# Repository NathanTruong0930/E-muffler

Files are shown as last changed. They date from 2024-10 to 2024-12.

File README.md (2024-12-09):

**Exhaust System for Electric Vehicles**

This project aims to enhance the driving experience of electric vehicles by creating a system that mimics the sound of a traditional car engine. While electric vehicles are known for their quiet operation, some drivers miss the auditory feedback that comes with accelerating and driving. Our solution is a customizable exhaust system that produces realistic engine sounds and visually engages the user with LED indicators.

At the heart of the system is a custom-designed circuit board (PCB) that integrates key components like speakers, LEDs, touch sensors, and a throttle positioning sensor. The sounds are stored on a microSD card and played through dual speakers. One speaker produces a constant background hum, while the other changes its volume based on the throttle position, simulating acceleration. The system also features LED lights to indicate power status and track selection.

The exhaust system is user-friendly and easy to control. A touch sensor lets the user turn the system on and off, while another sensor allows switching between different engine sound profiles. The LED lights indicate whether the system is on and show which sound profile is currently active. Powered by a standard 9V battery, the entire setup is compact enough to fit inside an exhaust-like enclosure, making it ideal for integration into an electric vehicle.

This project combines practical engineering with creativity, offering a solution that balances the silence of electric vehicles with the sensory experience of traditional cars. Whether you’re a car enthusiast or just someone looking for a fun way to personalize your EV, this exhaust system brings sound and style to the future of driving.

Team members:
- Nathan Truong
- Eisa ALsharifi
- Aziz Alshaanban
- Fernando Custodio Calderon

Project Schedule - [Gantt Chart](https://pdx127928.monday.com/boards/7800402463)

Note: The archive folder contains older revisions of homework files.

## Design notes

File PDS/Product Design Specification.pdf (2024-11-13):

ECE 411 Product Design Specification Team 14
Version 2.0
Nathan Truong, Eisa Alsharifi, Aziz Alshaanban, Fernando Custodio Calderon

Nov 13, 2024

Create a PDS for your practicum project, and upload it to your collaboration site. Sections should include:

Electric Vehicle Sound Muffler

Our product the Electric vehicle sound muffler is a device that makes electric vehicles sound like traditional gas powered cars. It’s designed for people with electric vehicles who want to have their vehicles sound like a traditional vehicle that has a powerful, loud engine.
Our product uses an accelerometer and a throttle position sensor to track the car's speed and movement. These sensors send information to the Arduino Uno. The sounds are played through speakers, allowing an engine revving noise to be heard that changes as the vehicle speeds up or slows down. Once installed, the muffler works automatically, generating powerful engine sounds as the vehicle drives. It gives drivers a more engaging experience, making it less boring when going on a ride. You won’t be bored with the sound of silence while driving anymore.

Our intended customers are anyone who has an electric vehicle and would like to have a better driving experience by adding the sound of a traditional car. Also our product would be great for just any car enthusiast.
Our main competition would be competitors who make third party noise systems and other types of sound generators made for electric vehicles. Our product stands out because it will use real-time sound based on how a vehicle is performing, thus making it feel like a more authentic experience.
Our product will be sold for somewhere between $200 - 300. We chose this price because it will cover the price of our components and remain affordable enough for anyone looking to enhance their driving experience in their electric vehicle.
- Requirements:
- The device MUST be compact and lightweight, SHOULD be easy to install. A complete beginner should be able to learn how to install this device in 10-15 minutes of reading the manual.
- The device MUST have low power consumption to avoid affecting the vehicle performance, SHOULD use energy-efficient components and sound amplification circuits. It MAY use a solar charging system or a rechargeable battery.
- The Sound frequency MUST be clear and realistic to match the accelerometer even at higher volumes. The product MUST be fully automated and reflects the real-time throttle data as well as the speed of the vehicle using CAN bus
- Safety is a MUST, It will have water resistance incase of rain and proper insulation incase of heat. To prevent any potential fire hazards.
- The total cost of the product should fall within the $200-300 price range.

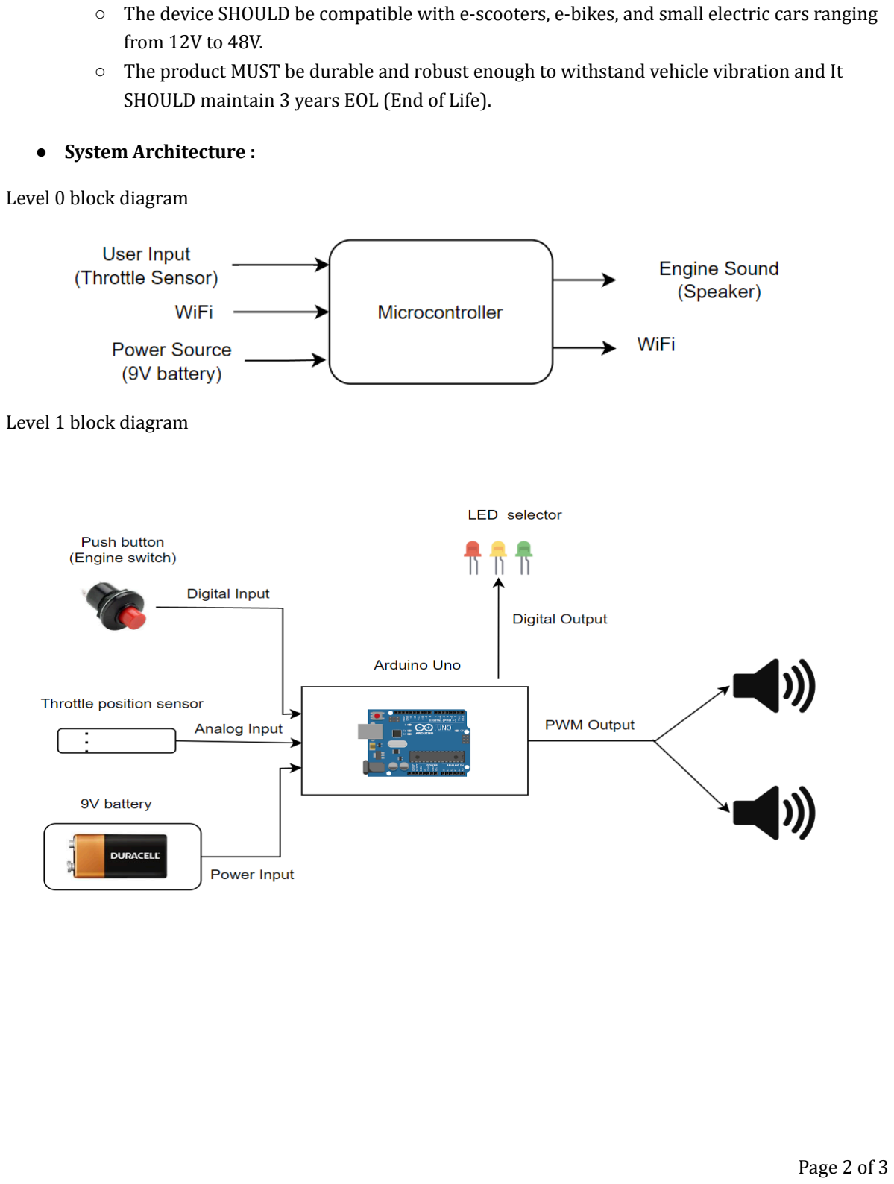
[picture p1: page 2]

- The device SHOULD be compatible with e-scooters, e-bikes, and small electric cars ranging from 12V to 48V.
- The product MUST be durable and robust enough to withstand vehicle vibration and It SHOULD maintain 3 years EOL (End of Life).
- System Architecture :

Level 0 block diagram

Level 1 block diagram

- Design Specification

❖ Sensors:
- Throttle Position Sensor: Simulates throttle input to determine the intensity of engine sound variations based on the vehicle’s simulated speed.
❖ Processor:
- Arduino Uno: Built into the custom PCB to process sensor data and produce required audio signals. The design contains all of the Arduino Uno's supporting components on the PCB.
❖ Actuator:
- 2 Speakers in Exhaust: The speakers will be installed inside an exhaust structure to replicate the acoustic environment of a traditional car exhaust. This setup will mimic sound propagation and improve the realistic feel of the created engine sounds.
- Audio Amplifier: The PCB will feature an amplifier that boosts audio signals before they are sent to the speakers.
❖ Power:
- 9V Battery: The entire system will be powered by a 9V battery, with onboard voltage regulation circuits to step down the voltage appropriately for the microcontroller, Wi-Fi module, and other components.
❖ Mechanical Design:
- The custom-designed PCB will be safely contained in the exterior like a car exhaust. The throttle position sensor will be programmed to collect precise data to power the sound generating algorithm.
❖ Firmware:
- The firmware on the Arduino Uno will process sensor data and make engine noises in response to simulated vehicle settings. The code will incorporate algorithms for making real-time sound modifications in response to changes in throttle input.
- The Wi-Fi module allows for remote monitoring or control, providing users to configure or alter sound parameters via a remote control.
❖ Development Environment:
- Arduino IDE: The firmware will be developed using the Arduino IDE, with an ICSP programmer used for uploading the code to the integrated Arduino Uno.
- Signal Processing Libraries: Custom libraries will be used to process data from sensors, generate sounds, and communicate over Wi-Fi.

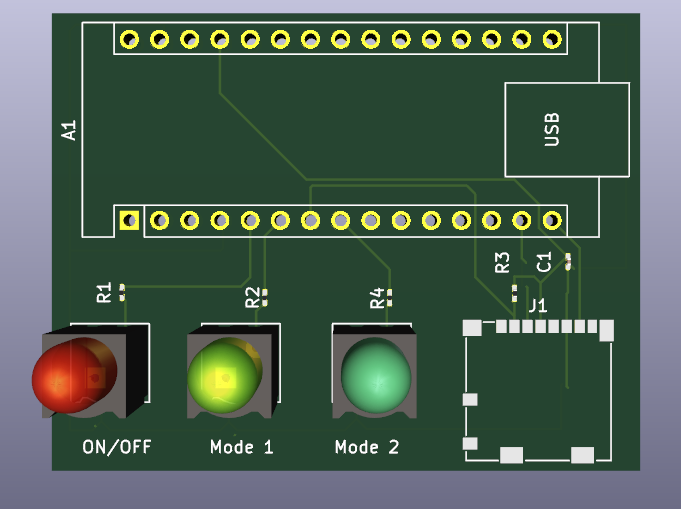
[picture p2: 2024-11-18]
Schematics/PCB-3D-View.PNG

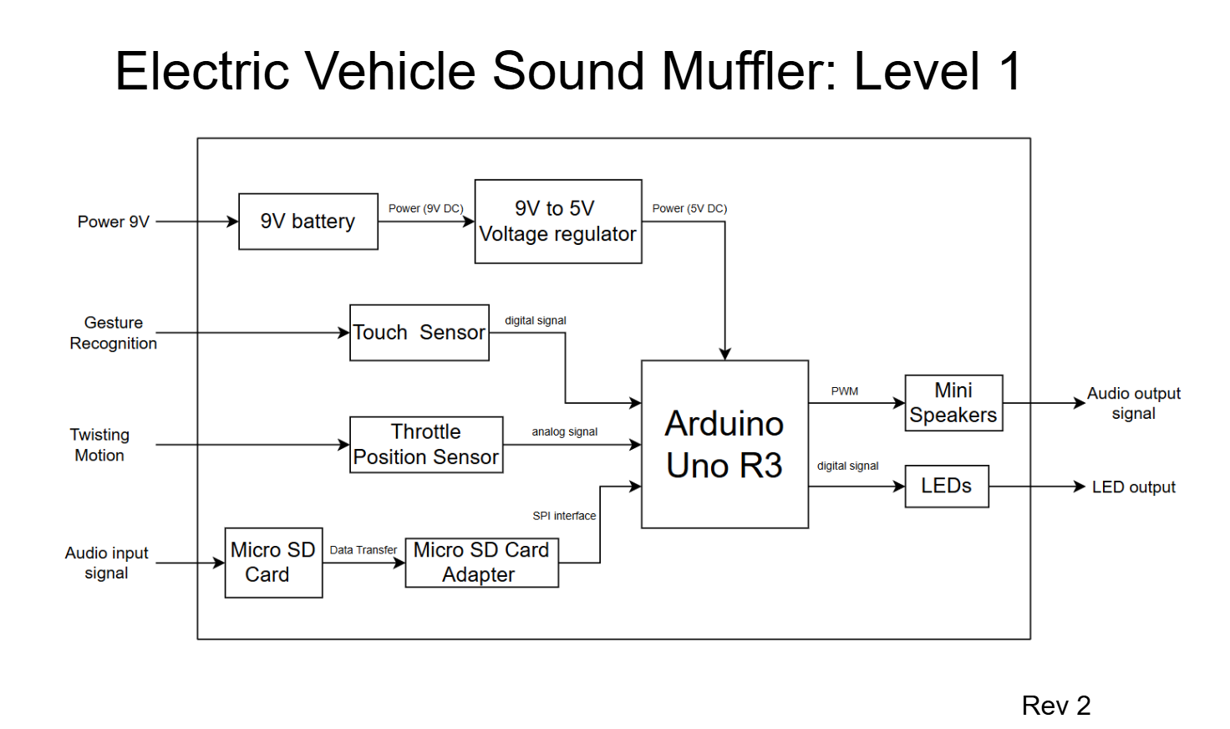
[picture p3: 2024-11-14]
Block Diagrams/L1 Diagram.png

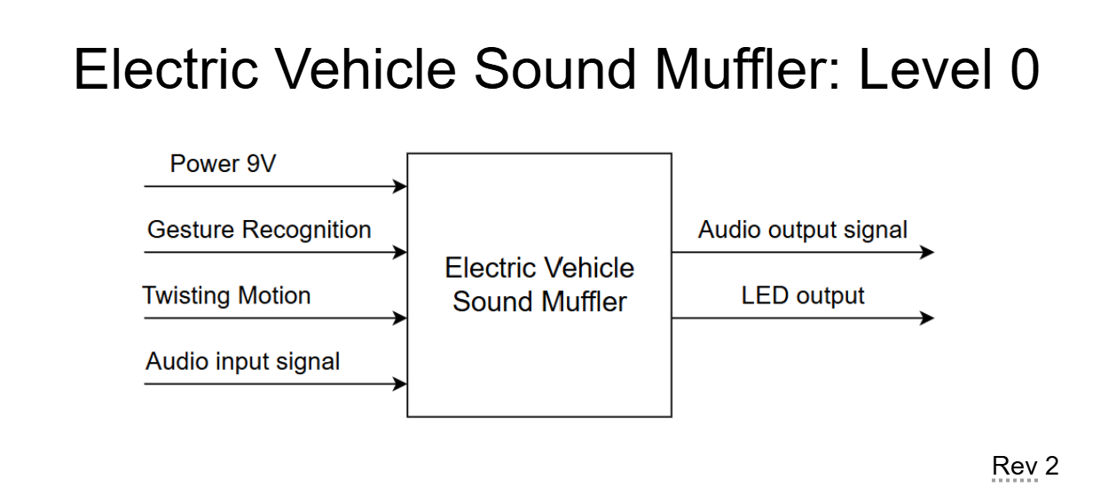
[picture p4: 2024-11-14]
Block Diagrams/L0 Diagram.png

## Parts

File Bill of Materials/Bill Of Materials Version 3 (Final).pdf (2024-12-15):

P/NP
Cnt Part References | P/NP | Mfg | Mfg PN | Description | Dist | Dist Part Number | Cost Total Datasheet
1 | A1 | P | LAFVIN | A000005 | x3 Nano V3.0, Nano Board ATmega328P 5V 16M Micro-Controller Board Compatible with Arduino IDE (Nano x 3 with USB Cable) Amazon | B07G99NNXL | $15.99 https://mm.digikey.com/Volume0/opasdata/d220001/medias/docus/382/A000005.pdf
1 | C1 | P | Murata Electronics | GRM31CR60J107KEA8L | CAP CER 100UF 6.3V X5R 1206 | Digi-Key | 490-GRM31CR60J107KEA8LCT-ND $0.54 https://search.murata.co.jp/Ceramy/image/img/A01X/G101/ENG/GRM31CR60J107KEA8-01A.pdf
1 | C2 | P | KEMET | C1206X106J3RACAUTO | CAP CER 10UF 25V X7R 1206 | Digi-Key | 399-15736-1-ND | $1.59 https://search.kemet.com/download/datasheet/C1206X106J3RACAUTO
1 | J1 | P | Molex | 1040310811 | 10 (8 + 2) Position Card Connector Secure Digital - microSD™ Surface Mount, Right Angle Gold Digi-Key | WM6357CT-ND | $2.30 https://www.molex.com/en-us/products/part-detail/1040310811?display=pdf
3 | R1, R2, R4 | P | Panasonic Electronic Components | ERJ-6ENF2200V | RES SMD 220 OHM 1% 1/8W 0805 | Digi-Key | P220CCT-ND | $0.052
3 | R3, R5, R6 | P | Panasonic Electronic Components | ERJ-6ENF1001V | RES SMD 1K OHM 1% 1/8W 0805 | Digi-Key | P1.00KCCT-ND | $0.052 https://industrial.panasonic.com/cdbs/www-data/pdf/RDA0000/AOA0000C304.pdf
1 | U1 | NP | SWCTSY | SW765071651710 | E-Bike Throttle Grip | Amazon | 765071651710 | $14.58 https://industrial.panasonic.com/cdbs/www-data/pdf/RDA0000/AOA0000C304.pdf
1 | U2, U3 | NP | Adafruit | 1375 | Standalone Toggle Capacitive Touch Sensor Breakout Adafruit | AT42QT1012 | $0.33
1 | U4 | P | Texas Instruments | LM7805CT/NOPB | IC REG LINEAR 5V 1A TO220-3 | Digi-Key | 296-47192-ND | $1.74 https://www.ti.com/lit/ds/symlink/lm7800.pdf
1 | LED1 | P | Dialight | 5612101060F | LED CBI 5MM RED TH PC MNT | Digi-Key | 350-2813-ND | $1.43 https://mm.digikey.com/Volume0/opasdata/d220001/medias/docus/932/561-zz0z-zzz.pdf
1 | LED2 | P | Dialight | 5612201060F | LED CBI 5MM GRN TH PC MNT | Digi-Key | 350-2374-ND | $1.52 https://mm.digikey.com/Volume0/opasdata/d220001/medias/docus/932/561-zz0z-zzz.pdf
1 | LED3 | P | Dialight | 5612301060F | LED CBI 5MM YELLOW TH PC MNT | Digi-Key | 350-3148-ND | $1.43 https://mm.digikey.com/Volume0/opasdata/d220001/medias/docus/932/561-zz0z-zzz.pdf
1 | SL, SR | NP | Esooho | EK1725 | Gikfun 2" 4Ohm 3W Full Range Audio Speaker Stereo Woofer Amazon | B01CHYIU26 | $9.99 https://www.amazon.com/Gikfun-Speaker-Stereo-Loudspeaker-Arduino/dp/B01CHYIU26
3 | Vbattery | NP | ZEUS Battery Products | ZEUS 9V | BATTERY ALKALINE 9V | Digi-Key | 2059-ZEUS9V-ND | $2.00 https://www.zeusbatteryproducts.com/wp-content/uploads/downloads/Zeus_Alkaline_9V_RevV2_spec_sheet.pdf
1 | VBat1 | P | Keystone Electronics | 81-4 | BATT CONNECTOR SNAP 9V 4" LEADS | Digi-Key | 36-81-4-ND | $0.67 https://www.keyelco.com/userAssets/file/M65p30.pdf
3 | U1, U2, U3 | P | Amphenol ICC | G800W305018EU | PIN HEADER 2.54MM PITCH STR,1X3P | Digi-Key | 664-G800W305018EU-ND$0.062 https://cdn.amphenol-cs.com/media/wysiwyg/files/drawing/g800wxxxxxxeu_1.pdf
3 | LS1, LS2 | P | Amphenol ICC | G800W306018EU | PIN HEADER 2.54MM PITCH STR,1X2P | Digi-Key | 664-G800W306018EU-ND$0.046 https://cdn.amphenol-cs.com/media/wysiwyg/files/documentation/datasheet/boardwiretoboard/bwb_btb_254_g800.pdf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
1 | EXH | NP | A-KARCK | N-ATP355012RACB | A-KARCK Exhaust Tip 3.5 Inch Inlet, 3.5” Inlet 5" Outlet 12" Long Stainless Steel Polished Finish Tailpipe Tip, Bolt On Design Amazon | 8.83343E+11 | $27.99 https://www.amazon.com/dp/B08CXNYXHZ?ref=ppx_yo2ov_dt_b_fed_asin_title&th=1
1 | Micro SD Card | P | MCG Bear LTD | SDSQUNB-032G-GN3MN SanDisk 32GB 32G Ultra Micro SD HC Class 10 TF Flash SDHC Memory Card - SDSQUNB-032G-GN3MN Amazon | B010NE3QHQ | $7.82 https://www.amazon.com/SanDisk-Ultra-SDSQUNB-032G-GN3MN-UHS-I-microSDHC/dp/B010NE3QHQ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
15 | Jumper Wires | P | | | | EPL | | $7.50
1 | PCB (OSH Park ~) | | | | | | | $8.18
1 | Shipping & Tariff | | | | | | | $20.41
| | | | | | | TOTAL: | $126.22

Bill Of Materials for: TEAM14, Exhaust System for Electric Vehicles
Last modified: 12-12-2024
PCB version: PCB VERSION #3
BOM revision: BOM REVISION #4 | = Place/Not Place (components marked NP are not stuffed on the board)

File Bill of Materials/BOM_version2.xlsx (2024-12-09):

Bill Of Materials for: TEAM14, Exhaust system for electric cars
Last modified: 11-14-2024
PCB version: PCB VERSION #1
BOM revision: BOM REVISION #1 |  | P/NP | = Place/Not Place (components marked NP are not stuffed on the board)
.
Cnt | Part References | P/NP | Mfg | Mfg PN | Description | Dist | Dist Part Number | Cost Ea. | Cost Total | Datasheet
1 | A1 | P | LAFVIN | A000005 | x3 Nano V3.0, Nano Board ATmega328P 5V 16M Micro-Controller Board Compatible with Arduino IDE (Nano x 3 with USB Cable) | Amazon | B07G99NNXL | $15.99 | $15.99 | https://mm.digikey.com/Volume0/opasdata/d220001/medias/docus/382/A000005.pdf
4 | C1 | P | Murata Electronics | GRM31CR60J107KEA8L | CAP CER 100UF 6.3V X5R 1206 | Digi-Key | 490-GRM31CR60J107KEA8LCT-ND | $0.54 | $2.16 | https://search.murata.co.jp/Ceramy/image/img/A01X/G101/ENG/GRM31CR60J107KEA8-01A.pdf
10 | C1 | P | Murata Electronics | 490-10387-1-ND | CAP CER 0.1UF 16V X7S 0201 | Digi-Key | 490-10387-1-ND | $0.018 | $0.18 | https://search.murata.co.jp/Ceramy/image/img/A01X/G101/ENG/GRM033C71C104KE14-01.pdf
4 | C2 | P | KEMET | C1206X106J3RACAUTO | CAP CER 10UF 25V X7R 1206 | Digi-Key | 399-15736-1-ND | $1.59 | $6.36 | https://search.kemet.com/download/datasheet/C1206X106J3RACAUTO
3 | J1 | P | Molex | 1040310811 | 10 (8 + 2) Position Card Connector Secure Digital - microSD™ Surface Mount, Right Angle Gold | Digi-Key | WM6357CT-ND | $2.30 | $6.90 | https://www.molex.com/en-us/products/part-detail/1040310811?display=pdf
2 | Q1, Q2 | P | Onsemi | LM317TG | Linear Regulators (LDO) | LM317 used for speakers | Digi-Key | LM317TG | $1.41 | $2.82
12 | R1, R2, R4 | P | Panasonic Electronic Components | ERJ-6ENF2200V | RES SMD 220 OHM 1% 1/8W 0805 | Digi-Key | P220CCT-ND | $0.052 | $0.62 | https://industrial.panasonic.com/cdbs/www-data/pdf/RDA0000/AOA0000C304.pdf
10 | R1, R2, R3 | P | Vishay Dale | CRCW0201220RFNED | 220 Ohms ±1% 0.05W, 1/20W Chip Resistor 0201 (0603 Metric) Thick Film | Digi-Key | 541-CRCW0201220RFNEDCT-ND | $0.038 | $0.38 | https://www.vishay.com/docs/20052/crcw0201e3.pdf
10 | R3, R5, R6 | P | Panasonic Electronic Components | ERJ-6ENF1001V | RES SMD 1K OHM 1% 1/8W 0805 | Digi-Key | P1.00KCCT-ND | $0.052 | $0.52 | https://industrial.panasonic.com/cdbs/www-data/pdf/RDA0000/AOA0000C304.pdf
4 | R1 | P | Vishay Dale | CRCW02011K00FKED | 1 kOhms ±1% 0.05W, 1/20W Chip Resistor 0201 (0603 Metric) Thick Film | Digi-Key | 541-1.00KAABCT-ND | $0.23 | $0.92 | https://www.vishay.com/docs/20052/crcw0201e3.pdf
1 | U1 | NP | SWCTSY | ‎SW765071651710 | E-Bike Throttle Grip | Amazon | ‎765071651710 | $14.58 | $14.58
1 | U2 | NP | Adafruit | 1375 | Standalone Toggle Capacitive Touch Sensor Breakout | Adafruit | AT42QT1012 | $0.33 | $0.33
3 | U4 | P |  |  |  |  |  |  | $0.00
3 | U4 | P | Texas Instruments | LM7805CT/NOPB | IC REG LINEAR 5V 1A TO220-3 | Digi-Key | 296-47192-ND | $1.74 | $5.22 | https://www.ti.com/lit/ds/symlink/lm7800.pdf
1 | Vhold | P | Adafruit | 80 | 9V battery clip with 5.5mm/2.1mm plug | Adafruit | 80 | $2.95 | $2.95
1 | VBat1 | P | Adafruit | 1321 | Alkaline 9V Battery | Digi-Key | 1321 | $1.50 | $1.50
3 | LED1 | P | Dialight | 5612101060F | LED CBI 5MM RED TH PC MNT | Digi-Key | 350-2813-ND | $1.43 | $4.29 | https://mm.digikey.com/Volume0/opasdata/d220001/medias/docus/932/561-zz0z-zzz.pdf
3 | LED2 | P | Dialight | 5612201060F | LED CBI 5MM GRN TH PC MNT | Digi-Key | 350-2374-ND | $1.52 | $4.56 | https://mm.digikey.com/Volume0/opasdata/d220001/medias/docus/932/561-zz0z-zzz.pdf
3 | LED3 | P | Dialight | 5612301060F | LED CBI 5MM YELLOW TH PC MNT | Digi-Key | 350-3148-ND | $1.43 | $4.29 | https://mm.digikey.com/Volume0/opasdata/d220001/medias/docus/932/561-zz0z-zzz.pdf
1 | LS1, LS2 | NP | Esooho | EK1725 | Gikfun 2" 4Ohm 3W Full Range Audio Speaker Stereo Woofer | Amazon | B01CHYIU26 |  | $0.00
3 | Vbattery | NP | ZEUS Battery Products | ZEUS 9V | BATTERY ALKALINE 9V | Digi-Key | 2059-ZEUS9V-ND | $2.00 | $6.00 | https://www.zeusbatteryproducts.com/wp-content/uploads/downloads/Zeus_Alkaline_9V_RevV2_spec_sheet.pdf
3 | VBat1 | P | Keystone Electronics | 81-4 | BATT CONNECTOR SNAP 9V 4" LEADS | Digi-Key | 36-81-4-ND | $0.67 | $2.01 | https://www.keyelco.com/userAssets/file/M65p30.pdf
10 | U1, U2, U3 | P | Amphenol ICC | G800W305018EU | PIN HEADER 2.54MM PITCH STR,1X3P | Digi-Key | 664-G800W305018EU-ND | $0.062 | $0.62 | https://cdn.amphenol-cs.com/media/wysiwyg/files/drawing/g800wxxxxxxeu_1.pdf
10 | LS1, LS2 | P | Amphenol ICC | G800W306018EU | PIN HEADER 2.54MM PITCH STR,1X2P | Digi-Key | 664-G800W306018EU-ND | $0.046 | $0.46 | https://cdn.amphenol-cs.com/media/wysiwyg/files/documentation/datasheet/boardwiretoboard/bwb_btb_254_g800.pdf
1 | Shipping & Tariff (First order) |  |  |  |  |  |  |  | $14.04
1 | Shipping & Tariff (Second order) |  |  |  |  |  |  |  | $13.41
VERSION INFO
 |  | Notes |  |  |  |  |  | TOTAL: | $111.11
Rev | Date | Cleaned up parts, rough draft of board
1.0r1 | 2024-11-14 | Initial BOM. Not everything chosen.
1.0r0 | 2020-11-12

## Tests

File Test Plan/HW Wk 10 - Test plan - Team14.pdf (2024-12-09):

ECE 411 Product Design Specification Team 14
Version 1.0
Nathan Truong, Eisa Alsharifi, Aziz Alshaanban, Fernando Custodio Calderon

Dec 08, 2024
Test Case

Test Author: Team 14
Test Case Name: | PCB Soldering Testing and Open Circuit Verification | Test ID #: | PCB-SOLDER-01
Description: | This test case focuses on verifying proper soldering of all PCB components, including resistors, capacitors, LEDs, and the SD card module. It ensures that all connections are free from open circuits, shorts, or improperly placed components. The test also includes steps to fix common issues such as flipped LEDs, poorly soldered components, or misaligned parts. | Type: | white box black box

Tester Information
| Name of Tester: | Eisa Alsharifi | Date: | 12/06/2024
| HW/SW Version: | 1.0 | Time: | 1:10-5:15 pm
| Setup: | Prepare a multimeter for continuity and voltage checks. Have a soldering station ready for rework. Connect a 9V battery to VBAT1 for power testing.
S T E P | Action | Expected Result | P A S S | F A I L | N / A | Comments
1 | Inspect solder joints on resistors (R1–R3). | All joints are clean and have no cold soldering or bridging. | ✔ | | | Resoldered R2 due to a cold joint.
2 | Inspect solder joints on capacitors (C1, C2). | Capacitors are soldered properly, with no open circuits or shorts. | ✔ | | | No issues detected.
3 | Check LED polarities and solder joints. | LEDs (R1, G1, Y1) are soldered properly; cathodes are not flipped. | | ✔ | | Cathode of LED R1 was flipped, fixed and retested.
2023-11-28 | Page 1 of 4

4 | Resolder flipped LED (if detected). | LED lights up correctly when powered. | ✔ | Verified LED R1 functionality after rework.
5 | Inspect SD card module soldering. | SD card pins are aligned and properly soldered with no open circuits. | ✔ | Pin alignment was off; resoldered successfully.
6 | Check for open circuits with a multimeter. | All resistors and capacitors show proper continuity. | ✔ | Continuity verified for all components.
7 | Test power delivery to the PCB. | 5V output is stable, with no shorts causing excessive current draw. | ✔ | Measured stable 5V output from Arduino Nano.
8 | Insert SD card and test initialization. | SD card initializes successfully, and data can be read. | ✔ | Initialization successful, SD card works as expected.
9 | Verify signal continuity for LEDs. | Multimeter shows continuity from the Arduino Nano to the LEDs. | ✔ | All LED connections verified.
| Overall test result: | | ✔ | Successful assembly

Matrix Test (for varying parameters)

Test Author: Team 14

Test Case Name: | PCB Testing and Component Verification | Test ID #: | PCB-TEST-01
Description: | This test case focuses on debugging the PCB build to ensure that all components are correctly soldered, powered, and function as intended. The test will verify the connections for power supply, LEDs, speakers, microSD card, and Arduino Nano integration. | Type: | white box black box

Tester Information

| Name of Tester: | Eisa Alsharifi | Date: | 12/06/2024
| HW/SW Version: | 1.0 | Time: | 6:10-10:15 AM
| Setup: | ● Power the PCB with a 9V battery via VBAT1. ● Connect a pre-programmed Arduino Nano. ● Ensure components (e.g., LEDs, speakers, microSD module) are properly soldered and connected. ● Use a multimeter and an oscilloscope for voltage and signal verification.
T ES T | INPUTS | EXPECTED OUTPUTS | P A S S | F A I L | N / A | Comments
1 | Inspect all solder joints visually. | No cold solder joints, shorts, or bridges are visible. | ✔ | | | All look good
2 | Power ON the PCB with 9V battery. | Verify 5V and 3.3V output at Arduino Nano pins. | ✔ | | | We indeed get 5V and 3.3V
3 | Check VBAT1 voltage with multimeter. | VBAT1 shows ~9V from battery. | | | ✔ | Wasn’t tested

4 | Check voltage at each LED pin. | LED pins should show expected voltage (e.g., ~2V for forward voltage). | | ✔ | We’re not able to get any readings to any LED
5 | Verify speaker connections (LS1, LS2). | Output terminals show audio signal when Arduino sends sound. | | ✔ | We get no sound, not even noise
6 | Test microSD card module functionality. | MicroSD is initialized, and files are accessible. | | ✔ | The adapter is soldered improbably
7 | Check throttle input (A0 pin). | Voltage changes as throttle sensor is adjusted. | ✔ | | We can get readings from the throttle
8 | Test ON/OFF touch sensor functionality. | LED toggles correctly between ON/OFF states. | | ✔ | It is powered, but doen’t function properly
9 | Test mode change touch sensor. | LEDs correctly indicate current track; audio switches accordingly. | | ✔ | It is powered, but doen’t function properly
10 | Adjust throttle to test volume control. | Speaker 1 volume adjusts with throttle input. | | ✔ | The readings are a bit off to were we wanted it to be
| Overall test result: | | | ✔ | We’ll fix all the issues and retest

Next testing will be on 12/10/2024 in the morning.

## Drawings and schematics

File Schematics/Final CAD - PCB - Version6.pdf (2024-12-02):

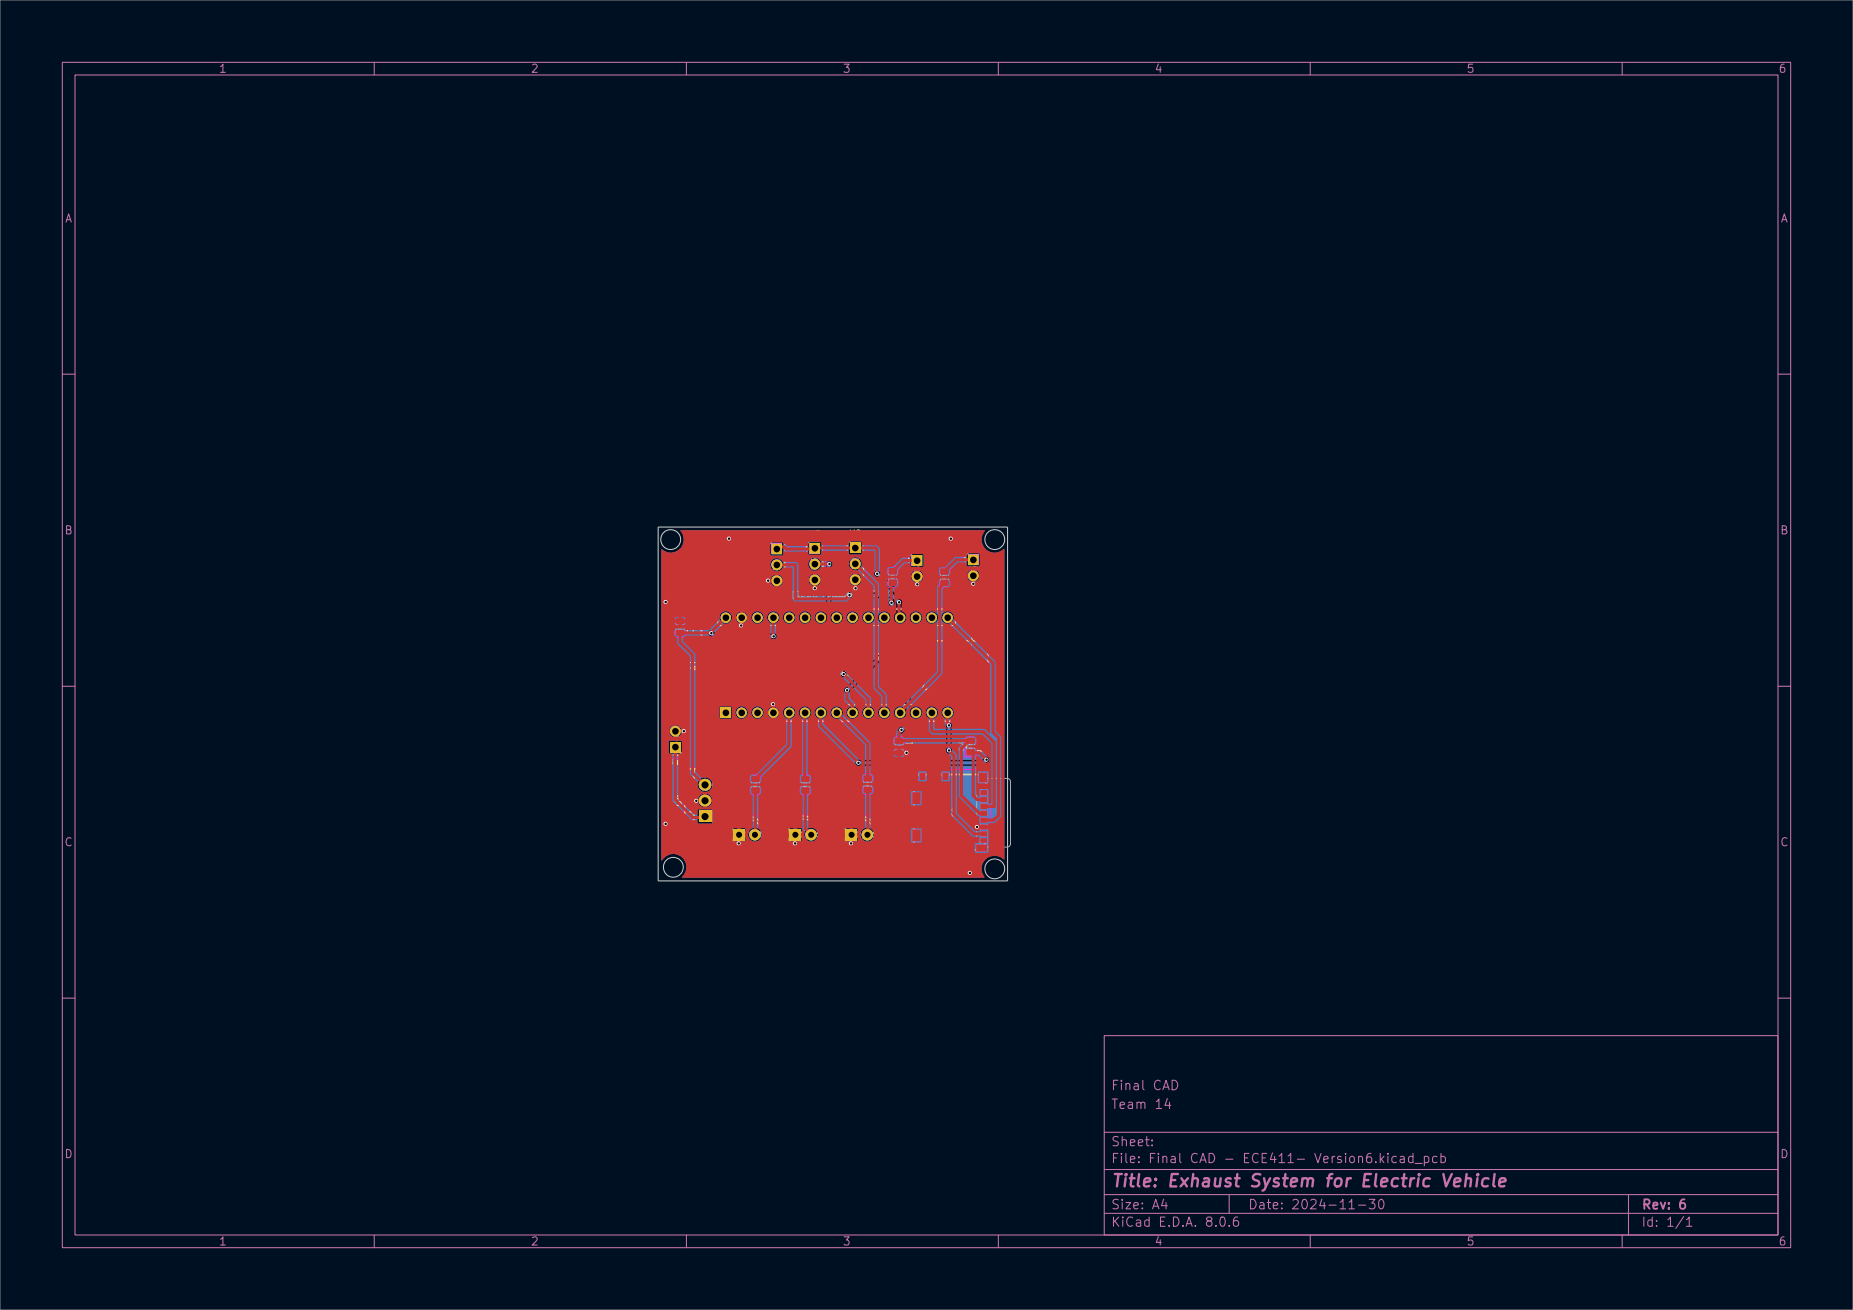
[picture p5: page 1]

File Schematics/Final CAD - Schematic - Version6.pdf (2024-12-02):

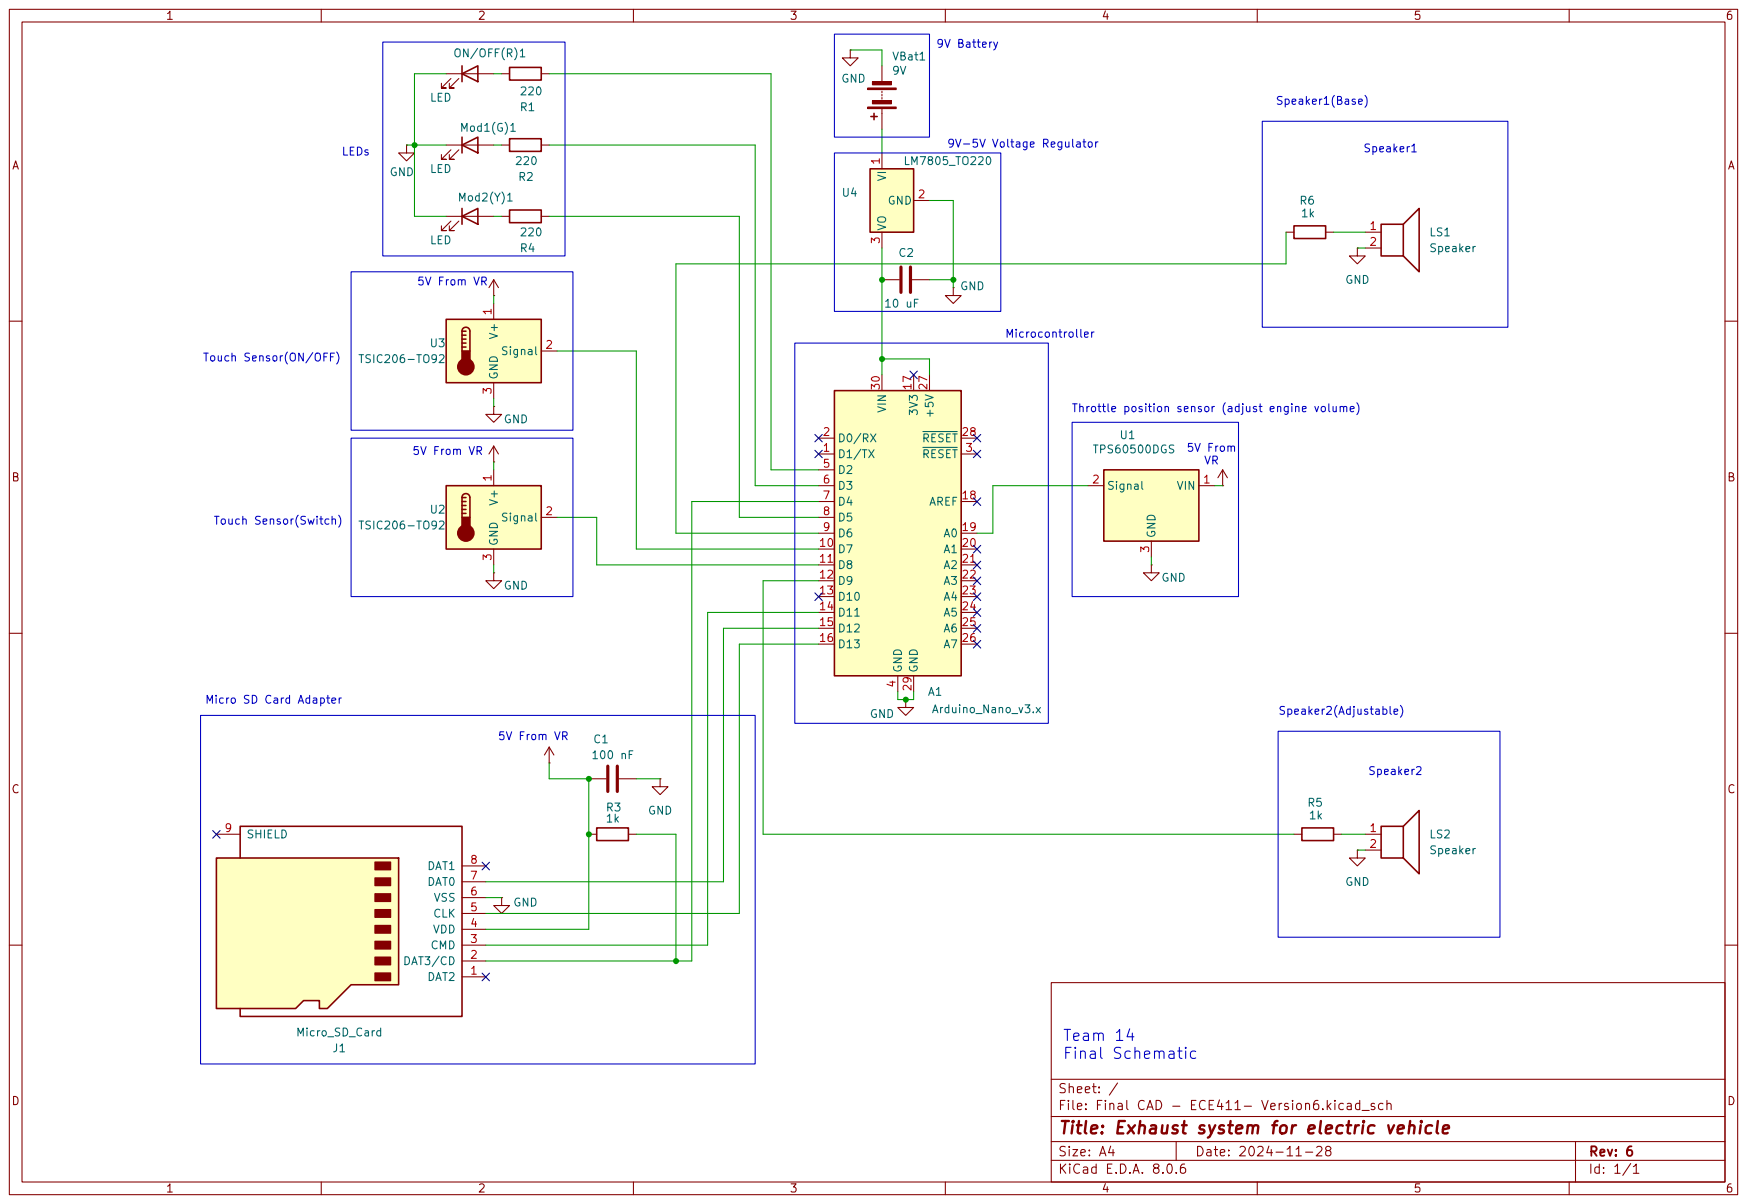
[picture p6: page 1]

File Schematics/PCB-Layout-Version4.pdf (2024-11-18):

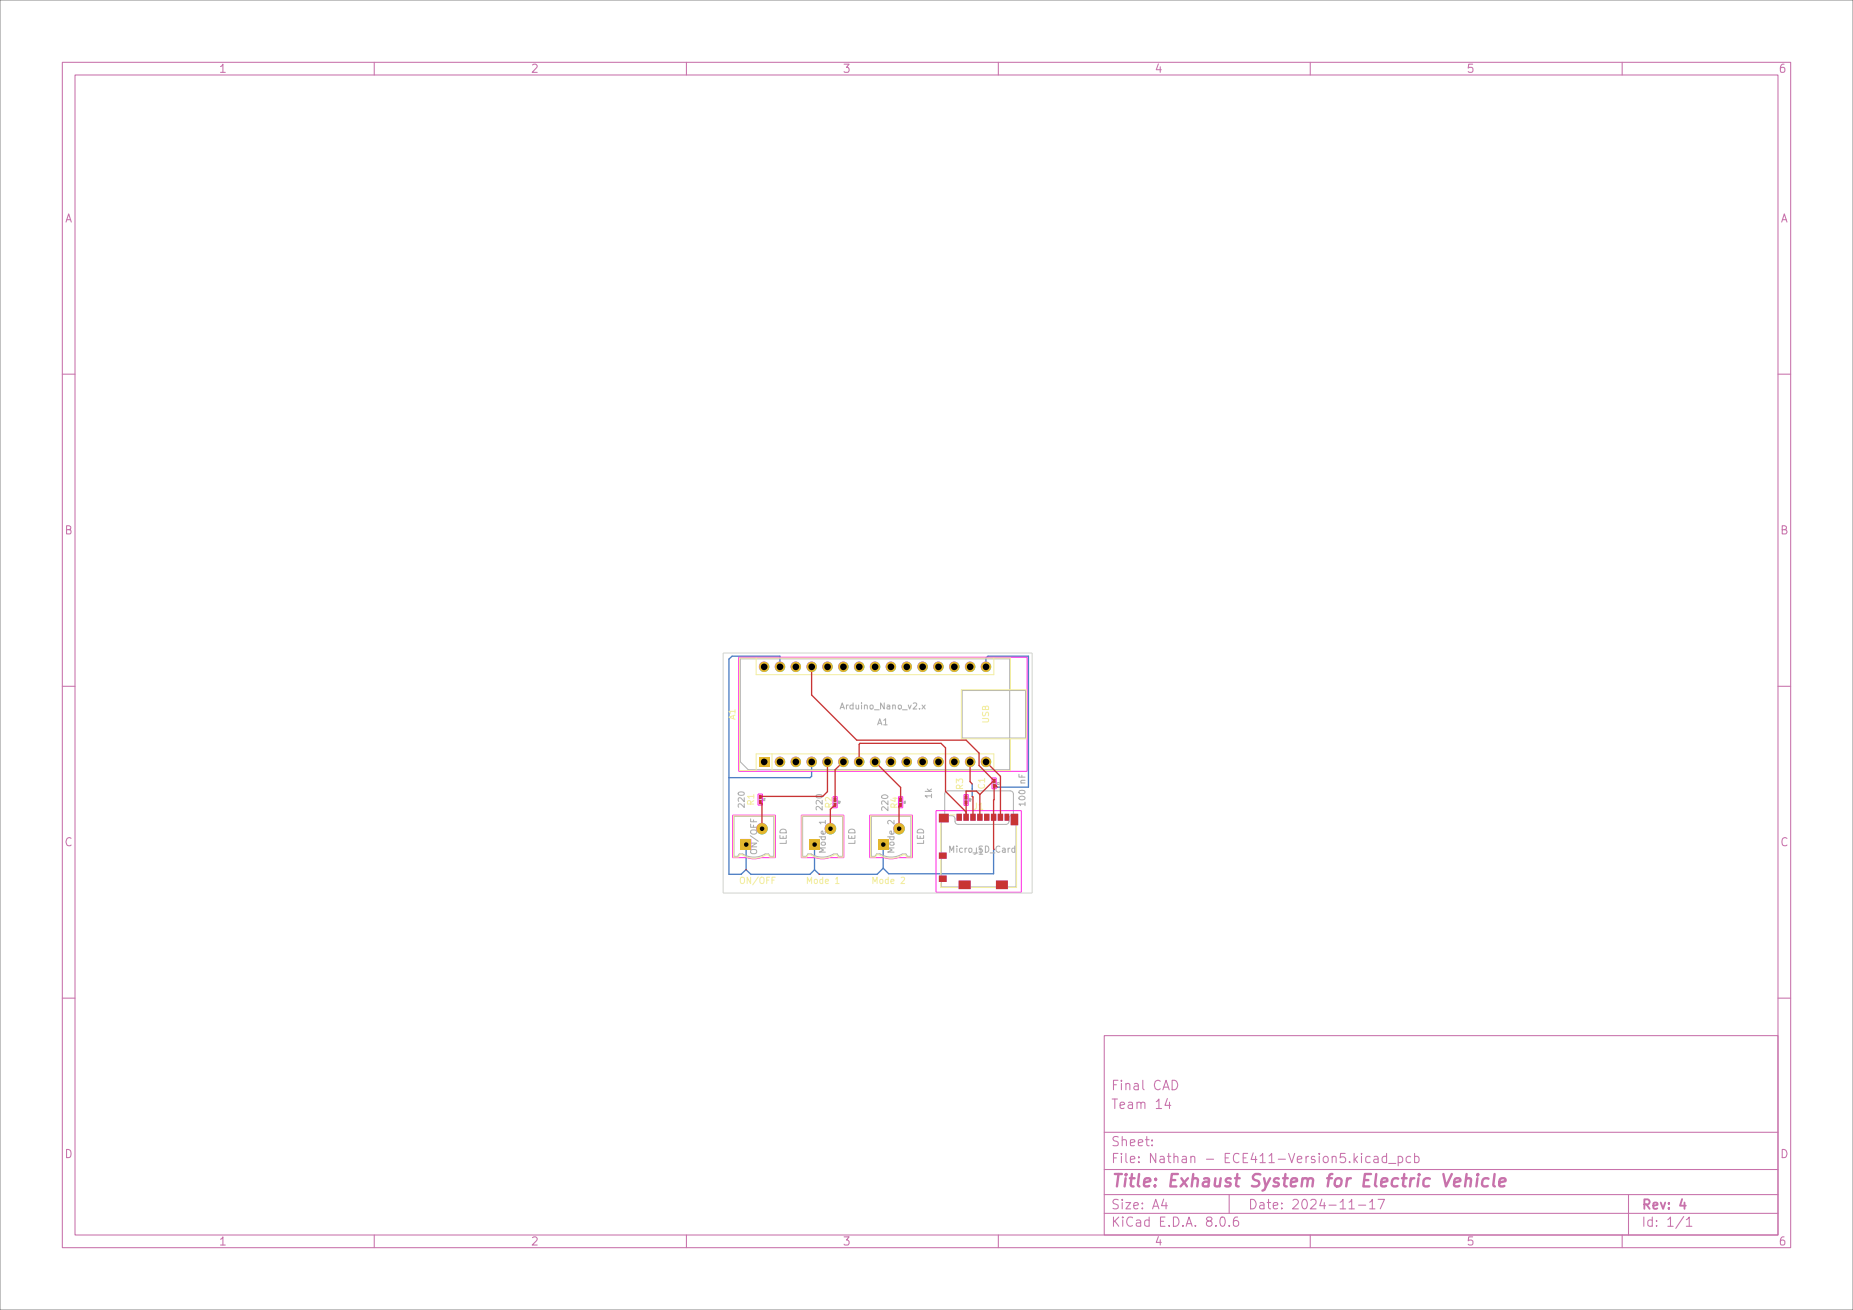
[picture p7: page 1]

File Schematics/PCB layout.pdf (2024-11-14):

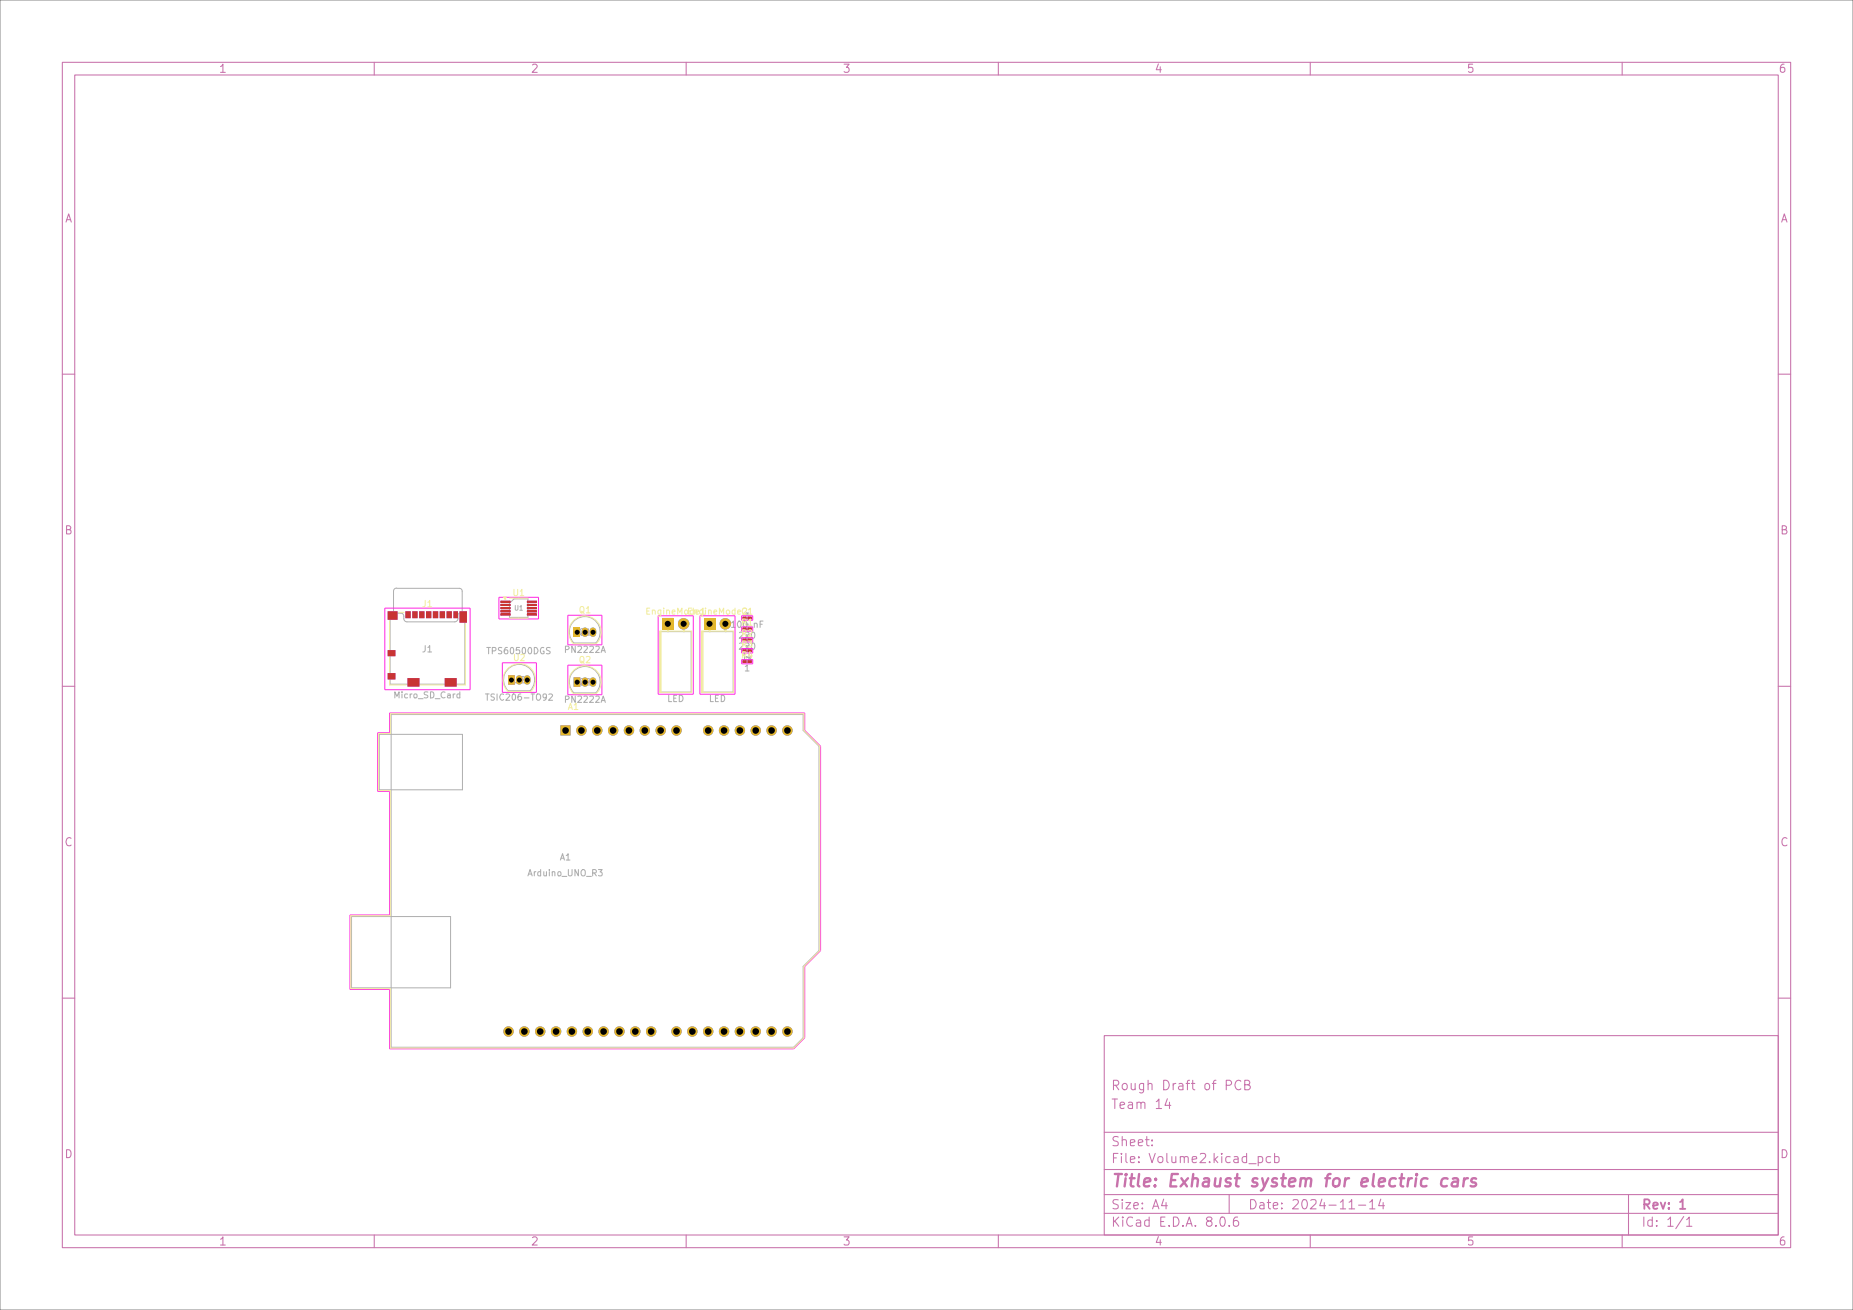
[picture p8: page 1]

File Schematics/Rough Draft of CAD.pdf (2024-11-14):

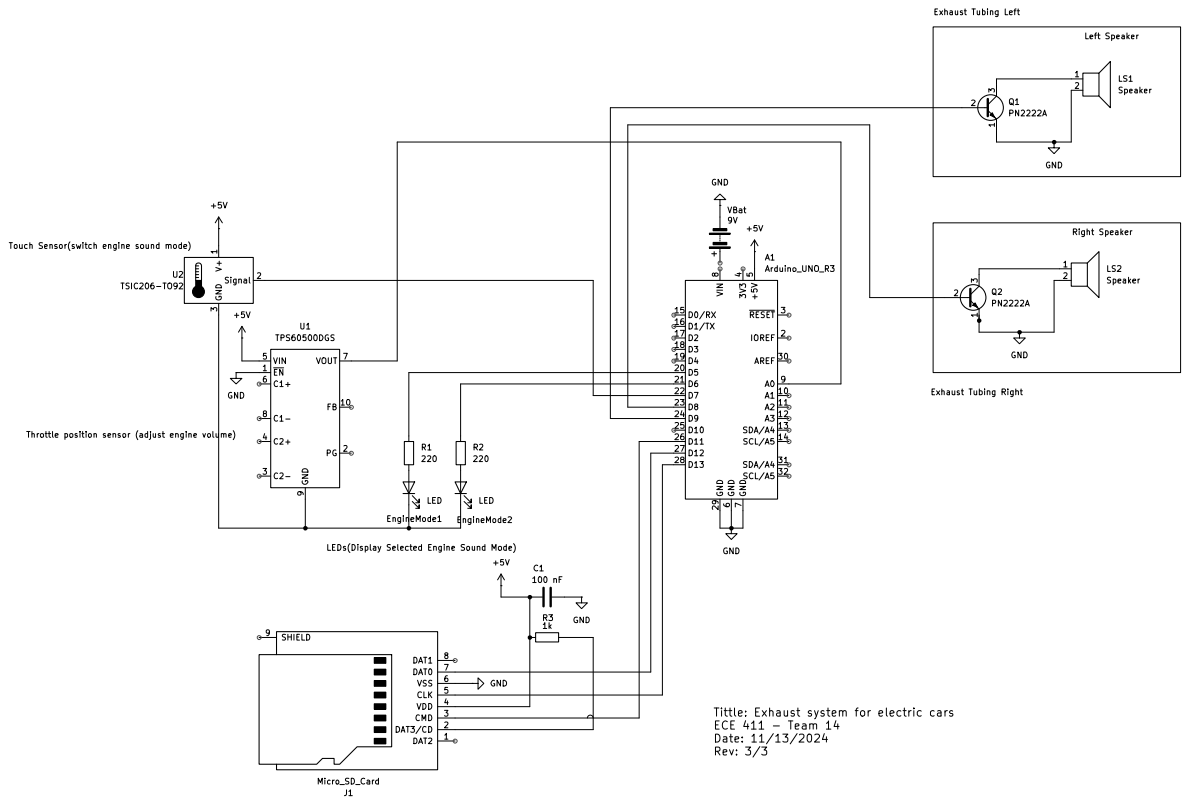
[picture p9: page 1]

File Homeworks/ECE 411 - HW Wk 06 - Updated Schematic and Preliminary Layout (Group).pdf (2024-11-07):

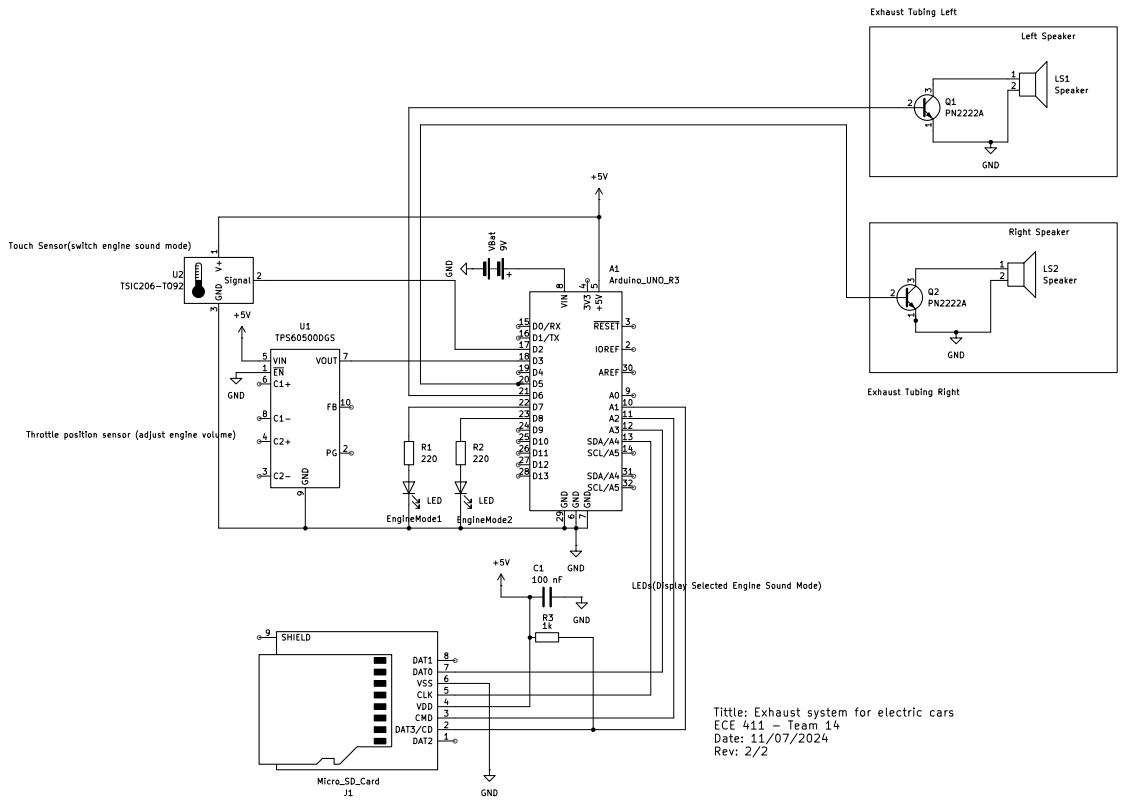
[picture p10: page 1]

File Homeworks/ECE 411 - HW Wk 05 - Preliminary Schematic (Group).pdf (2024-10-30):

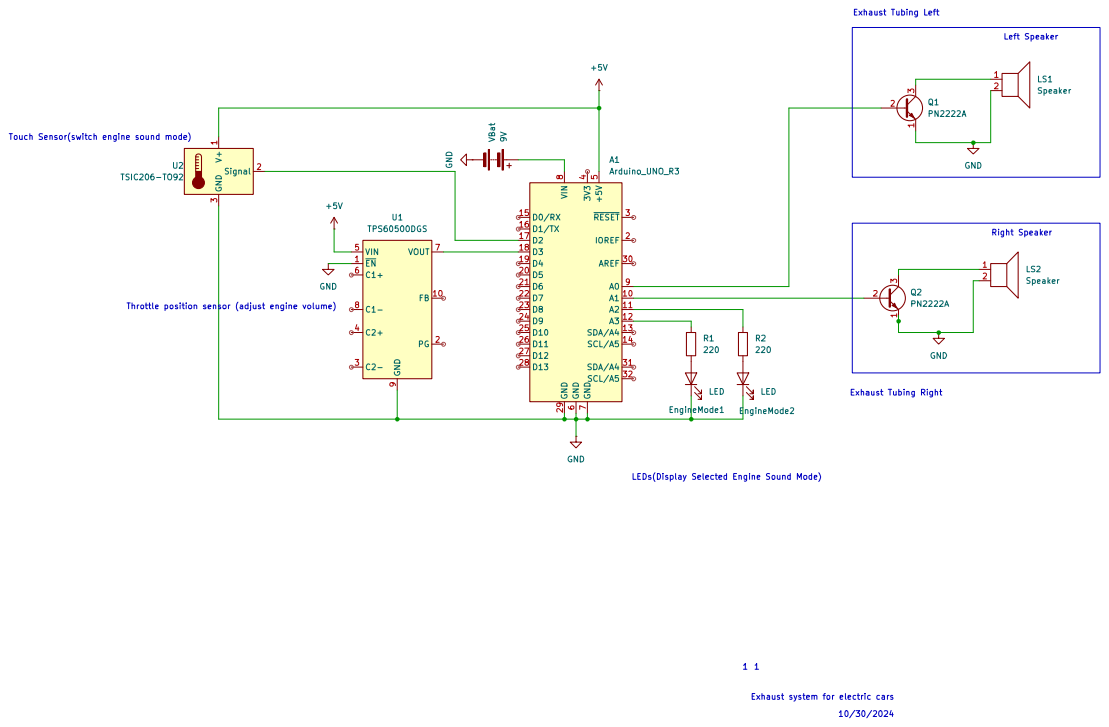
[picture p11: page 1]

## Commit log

2024-11-07 Rename HW Wk 06 - Show off Your Breadboard Prototype.pdf to ECE411 - HW Wk 06 - Show off Your Breadboard Prototype.pdf
2024-11-07 Create Schematics
2024-11-07 Rename schematic 4.pdf to Updated Schematic.pdf
2024-11-14 Rename preliminary schematic.pdf to ECE 411 - HW Wk 05 - Preliminary Schematic (Group).pdf
2024-11-14 Rename ECE 411 - Team 14 - HW Wk 06 - Updated Schematic and Preliminary Layout (Group).pdf to ECE 411 - HW Wk 06 - Updated Schematic and Preliminary Layout (Group).pdf
2024-11-14 Rename HW Wk 06 - Show off Your Breadboard Prototype.pdf to ECE 411 - HW Wk 06 - Show off Your Breadboard Prototype.pdf
2024-11-14 Rename ECE 411 - HW Wk 07 - Rough Draft of CAD (Group).pdf to Rough Draft of CAD.pdf
2024-11-14 Rename ECE 411 - HW Wk 07 - PCB layout.pdf to PCB layout.pdf
2024-11-14 Rename HW Wk 07 - Bill of Materials (BOM) (Team 14).xlsx to BOM.pdf
